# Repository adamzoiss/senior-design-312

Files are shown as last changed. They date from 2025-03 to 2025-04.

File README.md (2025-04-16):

# Senior Design Project - Team 312

**Share Point Quick Link:** [Project SharePoint](https://fsu-my.sharepoint.com/personal/amw21i_fsu_edu/_layouts/15/Doc.aspx?sourcedoc={c8d6e6cb-04f5-4a5c-a4a4-ac70581ecfba}&action=edit&wd=target%28Class%20Handouts.one%7C43749e4e-c570-4688-8d40-703e8b013bf2%2FSenior%20Design%20Projects%7C01b6a98f-3880-41ca-834b-d67c770890d6%2F%29&wdorigin=NavigationUrl)

---

**Table of Contents**

> _The links are clickable and will take you to that section or subsection._

- [**Operation Manual**](#operation-manual)

  - [How to start the device](#how-to-start-the-device)
  - [How to operate](#how-to-operate)

- [**Project Description**](#project-description)

  - [Overall Processes](#overall-processes)
  - [Audio Processing and Transmission](#audio-processing-and-transmission-of-data)
  - [Encryption/Decryption Information](#how-the-encryption-and-decryption-works)
  - [Materials](#materials)

- [**RPI Setup**](#rpi-setup)

  - [Flashing an OS](#flashing-an-os)
  - [How to SSH to rpi](#how-to-ssh-to-rpi)
  - [Driver Installation](#driver-installation)

- [**Coding Environment**](#coding-environment)

  - [Running the Code](#running-the-code)

- [**Creating a daemon**](#creating-a-daemon)

- [**Using Git**](#using-git)

  - [Setting up Git](#setting-up-git)
  - [Git usage](#git-usage)

- [**Documenting Python Code**](#documenting-python-code)

  - [Code Documentation](#code-documentation)
  - [Type Hinting Guide](#type-hinting-guide)

- [**Contributors**](#contributors)

**Resources:**

[KiCad](https://www.kicad.org/) - The circuit schematic and PCB design files are in the kicad folder.

[PEP 8 – Style Guide for Python Code](https://peps.python.org/pep-0008/#introduction) - Guideline for how to code in Python

[Python Project/Package Template](https://github.com/pypa/sampleproject) - To better understand the structure of the project, a template for python projects/packages can be viewed as a reference.

[Raspberry Pi pinout information](https://pinout.xyz/) - Useful for setting up buttons, switches, RF chip, etc. via the GPIO pins.

[Git Information](https://git-scm.com/book/en/v2) - Information on how to use git.

---

## Operation Manual:

A Guide on how to operate the end project will be discussed in this section.

### How to start the device:

Ideally a daemon could be used to start the program when booted up but there was a bug where the audio volume would only be set to 50%. The surefire way to get the device up and running is to first log in to the RPI5s and then configure it and and run the program manually:

```
alsamixer
```

- Set the volume to 100%

```
cd git/senior-design-312
penva
python src/managers/interface_manager.py
```

- This will start the program and show the logs in the terminal window

### How to operate

On the OLED screen there are two menus, Settings, and mode.

The Settings menu allows for the user to select and deselect the encryption for the device.

```
PENC - Packet Encryption: This is enables or disables the transceivers on board AES encryption.

DENC - Data Encryption: THis enables or disables the software encryption of the data.
```

In the Mode menu, the user can select the desired type of encryption for the data.

```
AES - Standard AES-256 Encryption

RSA - (NOT IMPLEMENTED) RSA Encryption

HYB - Hybrid Encryption method: RSA encrypted AES key
```

---

Volume Control

- The rotary encoder is used to change the onboard volume, which can be seen at the top left of the screen.

Selection of menu options

- The center button is used to select options in the menu.

Returning to the main menu

- The left button is used to return to the home screen.

Navigation

- The up and down buttons navigate through the menus.

Transmitting

- Pressing and holding the right button will start the transmission of the voice data from one device to the other. Releasing it will stop the transmission. Like a walkie-talkie, only one transceiver can be transmitting at a time.

---

## Project Description:

The purpose of the project is to have a hardware implementation for voice encryption. The approach taken was to use two Raspberry Pi 5's that are capable of encrypting and decrypting audio streams using AES or RSA. The encrypted stream is then sent to another Raspberry Pi via the RFM69 915MHz transceiver where it is then decrypted and played back. The functionality is like that of a rudimentary military grade radio (encrypted walkie talkie).

### Overall Processes:

To record the audio a button on the device is pressed, starting a thread to handle recording the audio and then transmitting it as shown in the diagram. The receiving device, upon receiving the RF signal and start sequence will start playing back the audio.

```mermaid
%%{init: {'theme': 'default', 'themeVariables': { 'fontSize': '18px', 'fontFamily': 'arial', 'edgeLabelBackground':'#ffffff'}, 'flowchart': {'diagramPadding': 40, 'curve': 'linear'}} }%%
flowchart LR
    %% Increase arrow thickness
    linkStyle default stroke-width:3px;

    subgraph sender["Audio Transmission"]
        record["Record Audio"] --> process["Process Audio"]
        process --> encode["Encode Audio"]
        encode --> encrypt["Encrypt Data"]
        encrypt --> send["Send Data"]
    end

    subgraph receiver["Reception and Playback"]
        receive["Receive Data"] --> decrypt["Decrypt Data"]
        decrypt --> decode["Decode Audio"]
        decode --> playback["Playback Audio"]
    end

    sender <==> receiver

    classDef default fill:#f0f8ff,stroke:#333,stroke-width:2px;
    classDef process fill:#e6ffe6,stroke:#333,stroke-width:2px;
    classDef encrypt fill:#ffe6e6,stroke:#333,stroke-width:2px;

    class record,process,encode,encrypt,send,receive,decrypt,decode,playback process;
```

### Audio Processing and Transmission of data:

[Diagrams and information](docs/design_flow_diagrams.md)

### How the encryption and decryption works:

This design used AES 256, RSA 4096, and a hybrid method that is outlined below:
[AES-256](docs/aes.md)
[RSA-4096](docs/rsa.md)

### Materials:

- [Raspberry Pi 5](https://www.adafruit.com/product/5813)
- [RPI UPS](https://www.amazon.com/Geekworm-X1200-Raspberry-Shutdown-Detection/dp/B0CRYVC8C5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)
- [ANO Directional Navigation](https://www.adafruit.com/product/5001)
- [RFM69HCW Transceiver](https://www.adafruit.com/product/3070)
- [Voice Bonnet](https://www.adafruit.com/product/4757)
- [OLED Display](https://www.amazon.com/dp/B0CHF7LHVT?ref=ppx_yo2ov_dt_b_fed_asin_title&th=1)
- [Speaker](https://www.adafruit.com/product/4227)

---

## RPI Setup:

### Flashing an OS:

1. Download the [Raspberry PI imager](https://www.raspberrypi.com/software/)

2. Select RPI 5 as device and Raspian 64-bit Lite as OS
   2.1 - For all the drivers for this project, a non desktop version must be used.

3. Customize settings before flashing

   - Name the device (ex. rpi5-312)
   - Set username (ex. team312)
   - Set password (ex. password)
   - Enable SSH in second tab
   - Finally flash the SD card with the OS

4. Plug SD card in, power on

---

### How to SSH to rpi:

_This step is optional_

Using powershell or terminal (must be on same network)

```bash
ssh [username]@[device name].local
```

- Follow steps to allow connection

- To make life simpler going forward, get the VS code extension _Remote Explorer_
  - Then follow steps to make a SSH connection in VS code.

---

### Driver Installation:

- This will update all the base packages and drivers for the Raspberry Pi.

  ```bash
  sudo apt update
  sudo apt -y upgrade
  sudo reboot
  ```

  - The following steps are for ease of installation of all the necessary packages/drivers for the RPI. Running the setup script will install all the packages as well as create a virtual python environment in the _senior-design-312_ directory.

  - This script also adds aliases to the .bashrc and exports the directory of the project to PYTHONPATH.

  ADDED ALIASES:

  - ptree - shows the tree of the directory, excludes some of the unimportant files.
  - penvca - Creates and activates a python virtual environment in _**.env**_
  - penva - Activates the python virtual environment.

  ```bash
  sudo apt install -y git
  mkdir git
  cd git
  git clone https://github.com/adamzoiss/senior-design-312.git
  cd senior-design-312
  cd setup_utils
  chmod +x setup.sh
  ./setup.sh
  ```

  - After the reboot, change the directory to _senior-design-312_ and run:

    ```bash
    penva
    ```

  All of the code should now be ready to run in the project.

---

## Coding Environment:

- When running the code ensure that the virtual environment is activated, if the setup script was run, in the project directory, run:
  ```bash
  penva
  ```

---

### Running the Code:

- Assuming the setup script was run to configure the RPI, ensure the virtual environment is activated (.env) to the left of your bash info, and run:

  ```bash
  python "path to python program"
  ```

- To run the tests and view the statistics, run:
  ```bash
  pytest
  ```

---

## Creating a daemon:

A daemon is a background process that runs continuously and independently of user interaction. It starts at boot (or when needed) and runs in the background, typically without a graphical interface. Daemons are often used for tasks like logging, networking, and running services (like web servers, audio managers, etc.). In the case of this project, a daemon is used to start the interface manager program on boot, and if it crashes, restarts the program.

- Creating a Systemd Service:
  ```bash
  sudo nano /etc/systemd/system/run-py-program.service
  ```
  > This should be pasted and modified to use the correct python path, program directory, and _pi_ username

```
[Unit]
Description=My Python Script Daemon
After=network.target sound.target
Wants=pulseaudio.service

[Service]
ExecStart=/home/pi/git/senior-design-312/.env/bin/python /home/pi/git/senior-design-312/src/managers/interface_manager.py
WorkingDirectory=/home/adamzoiss/git/senior-design-312
Environment="PYTHONPATH=/home/pi/git/senior-design-312"
User=pi
Group=pi
Restart=always
RestartSec=5
StandardOutput=append:/home/pi/git/senior-design-312/logs/system.log
StandardError=append:/home/pi/git/senior-design-312/logs/system.err

[Install]
WantedBy=multi-user.target
```

- Allow Systemd to use pulse audio:

  > By default, PulseAudio does not allow system services to access it. Run:

  ```
  sudo nano /etc/pulse/client.conf
  ```

  - At the end of the file, add:
    ```
    autospawn = yes
    ```
  - Then restart pulseaudio
    ```
    pulseaudio -k
    pulseaudio --start
    ```

- Enabling and staring the daemon:

  > To apply the changes made in the _.service_ file:

  ```
  sudo systemctl daemon-reload
  ```

  > To enable:

  ```
  sudo systemctl enable run-py-program.service
  ```

  > To start:

  ```
  sudo systemctl start run-py-program.service
  ```

  > View the status:

  ```
  sudo systemctl status run-py-program.service
  ```

  - More useful commands:
    ```
    sudo systemctl disable run-py-program.service
    sudo systemctl stop run-py-program.service
    sudo systemctl restart run-py-program.service
    ```

---

## Using Git:

Git is a distributed version control system designed to track changes in source code during software development. It allows multiple developers to collaborate on a project by managing code changes, maintaining a history of modifications, and enabling branching and merging workflows. Git ensures code integrity and simplifies collaboration by providing tools to resolve conflicts and review changes.

### Setting up Git:

- First set username and password via:

  ```bash
  git config --global user.name "github username"
  git config --global user.email "github email"
  ```

  - To verify they were set correctly:
    ```bash
    git config --global -l
    ```

  1. Make a github account (Make sure you set your username and email in global config)
  2. install _gh_ for github authentication
     ```bash
     sudo apt install gh
     gh auth login
     ```
  3. Follow steps and log in
  4. Verify with:
     ```bash
     gh auth status
     ```

---

### Git usage

- Always make edits in a `branch`, do not work directly on main. To see what branch is active:

  ```bash
  git branch
  ```

- To `checkout` an active branch with name _branchname_:

  ```bash
  git checkout branchname
  ```

- To create a new working branch:

  ```bash
  git checkout -b nameofbranch
  ```

- After making changes on a branch, save (`commit`) the changes by:

  ```bash
  git commit -a -m "brief description of what was done"
  ```

  - This saves the changes locally on your computer, to add (push the changes to github)
    ```bash
    git push origin branchname
    ```
    - Alternatively, If you want Git to automatically set upstream branches when pushing new local branches, you can enable:
      ```bash
      git config --global push.autoSetupRemote true
      ```
      This way, next time you create a new branch and push, Git will automatically set up the remote tracking branch. The command will now look like:
      ```bash
      git push
      ```

- Getting the most up to date code:
  - save changes that were done on your branch via a commit or stash
  - check out `main`
    ```bash
    git fetch
    ```
    ```bash
    git pull
    ```
  - the most up to date version of main is now what you see

---

## Documenting Python Code:

### Code Documentation

`numpy` style documentation is being used for this project.

**Example of a NumPy-style docstring:**

```python
import numpy as np

def compute_mean(arr):
    """
    Compute the mean of a NumPy array.

    Parameters
    ----------
    arr : numpy.ndarray
        Input array of numerical values.

    Returns
    -------
    float
        The mean (average) of the input array.

    Raises
    ------
    ValueError
        If the input is not a NumPy array.

    Examples
    --------
    >>> import numpy as np
    >>> arr = np.array([1, 2, 3, 4, 5])
    >>> compute_mean(arr)
    3.0
    """
    if not isinstance(arr, np.ndarray):
        raise ValueError("Input must be a NumPy array.")
    return arr.mean()
```

**Breakdown of the NumPy docstring format:**

- Short summary: The first line briefly describes what the function does.
- Parameters: List of arguments, types, and descriptions.
- Returns: Description of the return value and type.
- Raises: Expected exceptions that may be thrown.
- Examples: Demonstrates usage with `doctest`-style examples.

---

**Class with NumPy-style Docstrings**

This class represents a **Simple Linear Regression** model.

```python
import numpy as np

class SimpleLinearRegression:
    """
    A simple linear regression model using the least squares method.

    Attributes
    ----------
    coef_ : float
        The slope (coefficient) of the regression line.
    intercept_ : float
        The y-intercept of the regression line.

    Methods
    -------
    fit(X, y)
        Fits the model to the data.
    predict(X)
        Predicts values using the trained model.
    """

    def __init__(self):
        """
        Initializes the SimpleLinearRegression model with no trained parameters.
        """
        self.coef_ = None
        self.intercept_ = None

    def fit(self, X, y):
        """
        Fit the linear regression model to the given dataset.

        Parameters
        ----------
        X : numpy.ndarray
            Feature array of shape (n_samples,).
        y : numpy.ndarray
            Target array of shape (n_samples,).

        Raises
        ------
        ValueError
            If `X` and `y` have different lengths.

        Examples
        --------
        >>> import numpy as np
        >>> X = np.array([1, 2, 3, 4, 5])
        >>> y = np.array([2, 4, 6, 8, 10])
        >>> model = SimpleLinearRegression()
        >>> model.fit(X, y)
        """
        if len(X) != len(y):
            raise ValueError("X and y must have the same length.")

        X_mean = np.mean(X)
        y_mean = np.mean(y)

        num = np.sum((X - X_mean) * (y - y_mean))
        den = np.sum((X - X_mean) ** 2)

        self.coef_ = num / den
        self.intercept_ = y_mean - self.coef_ * X_mean

    def predict(self, X):
        """
        Predict the target values for given input data.

        Parameters
        ----------
        X : numpy.ndarray
            Feature array of shape (n_samples,).

        Returns
        -------
        numpy.ndarray
            Predicted values based on the trained model.

        Raises
        ------
        ValueError
            If the model has not been trained yet.

        Examples
        --------
        >>> import numpy as np
        >>> X = np.array([6, 7, 8])
        >>> model = SimpleLinearRegression()
        >>> model.fit(np.array([1, 2, 3, 4, 5]), np.array([2, 4, 6, 8, 10]))
        >>> model.predict(X)
        array([12., 14., 16.])
        """
        if self.coef_ is None or self.intercept_ is None:
            raise ValueError("Model is not trained. Call `fit` first.")

        return self.coef_ * X + self.intercept_
```

**NumPy Docstrings Benefits**

- Structured and readable: Clearly defines parameters, return values, and exceptions.
- Works with auto-documentation tools like Sphinx.
- Encourages best practices: Makes it easier to maintain and understand code.

---

### Type Hinting Guide:

1. Function Arguments & Return Types

   ```python
   def add(x: int, y: int) -> int:
       return x + y
   ```

   `x: int` and `y: int` specify that x and y should be integers.

   `-> int` means the function returns an integer.

2. Variable Annotations

   ```python
   name: str = "Alice"
   age: int = 25
   height: float = 5.9
   is_active: bool = True
   ```

3. Lists, Tuples, and Dictionaries

   Use `list`, `tuple`, and `dict` with generic types:

   ```python
   from typing import List, Tuple, Dict

   numbers: List[int] = [1, 2, 3, 4]
   point: Tuple[float, float] = (3.5, 7.2)
   person: Dict[str, int] = {"age": 30, "score": 95}
   ```

- `List[int]`: A list of integers.
- `Tuple[float, float]`: A tuple with two floats.
- `Dict[str, int]`: A dictionary with string keys and integer values.

4. Optional & Union Types

   **Optional Type (Allows `None`)**

   ```python
   from typing import Optional

   def get_user_name(user_id: int) -> Optional[str]:
       return "Alice" if user_id == 1 else None
   ```

   `Optional[str]` is equivalent to `Union[str, None]`.

   **Union (Multiple Types Allowed)**

   ```python
   from typing import Union

   def parse_value(value: Union[int, str]) -> str:
       return str(value)
   ```

   `Union[int, str]` means `value` can be an **int** or **str**.

5. Custom Classes as Types

   ```python
   class User:
       def __init__(self, name: str):
           self.name = name

   def greet(user: User) -> str:
       return f"Hello, {user.name}!"
   ```

   The function `greet` expects a `User` instance.

6. Callable (Hinting Functions)

   ```python
   from typing import Callable

   def execute(func: Callable[[int, int], int], x: int, y: int) -> int:
       return func(x, y)

   def multiply(a: int, b: int) -> int:
       return a * b

   result = execute(multiply, 3, 4)  # Returns 12
   ```

   `Callable[[int, int], int]` means a function that:

   - Takes two integeres.
   - Returns an integer.

7. Type Aliases (For Readability)

   ```python
   from typing import List

   Coordinates = List[Tuple[float, float]]  # Type alias

   route: Coordinates = [(10.0, 20.0), (30.5, 40.2)]
   ```

   Now, `Coordinates` can be used instead of `List[Tuple[float, float]]`.

8. Type Variables (For Generic Functions & Classes)

   _This is the same concept in C++ as `template <Typename T>`_

   ```python
   from typing import TypeVar, Generic

   T = TypeVar('T')  # Generic Type

   def repeat(value: T, times: int) -> List[T]:
       return [value] * times

   print(repeat("Hello", 3))  # ['Hello', 'Hello', 'Hello']
   ```

   Here:

   - `T` is a Type Variable that allows any type.
   - `repeat` works with any type, maintaining type safety.

9. TypedDict (For Struct-like Dictionaries)

   ```python
   from typing import TypedDict

   class UserDict(TypedDict):
       name: str
       age: int

   user: UserDict = {"name": "Alice", "age": 30}
   ```

   This ensures `user` has only the specified keys and types.

10. `Self` Type Hinting for Methods

    Introduced in Python 3.11, `Self` hints that a method returns an instance of its class.

    ```python
    from typing import Self

    class Animal:
        def set_name(self, name: str) -> Self:
            self.name = name
            return self  # Returns instance for method chaining

    dog = Animal().set_name("Buddy")
    ```

---

**Static Type Checking with `mypy`**

To enforce type checking, install mypy:

```bash
pip install mypy
```

Then run:

```bash
mypy my_script.py
```

This will flag type errors before runtime.

---

## Contributors:

Danielle Awoniyi : danielle1.awoniyi@famu.edu

Amira McKaige : amm21bc@fsu.edu

Amelia Wondracek : amw21i@fsu.edu

Travis Gabauer : tg21b@fsu.edu

Adam Zoiss : aez18@fsu.edu

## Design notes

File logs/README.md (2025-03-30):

This directory will hold the logs for the device.

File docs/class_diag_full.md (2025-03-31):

```mermaid
classDiagram
    class ThreadManager {
        - threads: dict[str, threading.Thread]
        - events: dict[str, threading.Event]
        - logger: logging
        + __init__()
        + start_thread(name, target, args)
        + stop_thread(name)
        + stop_all_threads()
        + pause_thread(name)
        + resume_thread(name)
        + is_running(name) bool
        + is_paused(name) bool
        + list_threads() list[str]
    }

    class CryptoManager {
        - key: bytes
        - iv: bytes
        - cipher: Cipher
        - key_file: str
        - public_key_file: str
        - private_key_file: str
        - logger: logging
        + __init__(key_file, public_key_file, private_key_file)
        + encrypt(data) bytes
        + decrypt(data) bytes
        - _load_key_iv() tuple
        - _load_rsa_keys() tuple
    }

    class BaseAudioManager {
        - CHUNK: int
        - FORMAT: pyaudio.paInt16
        - CHANNELS: int
        - RATE: int
        - audio: pyaudio.PyAudio
        - input_device_index: int
        - output_device_index: int
        - input_stream: pyaudio.Stream
        - output_stream: pyaudio.Stream
        - crypto_manager: CryptoManager
        - thread_manager: ThreadManager
        - logger: logging
        + __init__(thread_manager, frame_size, format, channels, sample_rate, in_device_index, out_device_index)
        + open_input_stream()
        + open_output_stream()
        + close_input_stream()
        + close_output_stream()
        + find_devices()
        + write_output(data, volume)
        + encode(data) bytes
        + decode(data) bytes
    }

    class AudioManager {
        + __init__(thread_manager, frame_size, format, channels, sample_rate, in_device_index, out_device_index)
        + monitor_audio(stop_event)
        + record_audio(output_file, monitoring)
        + record_encrypted_audio(output_file, monitoring)
        + encrypt_file(input_file, output_file)
        + decrypt_audio_file(input_file, output_file)
        + decrypt_audio_file_chunked(input_file, output_file)
        + record_encoded_audio()
        + play_encoded_audio()
    }
    AudioManager --|> BaseAudioManager

    class GPIOHandler {
        - handle: int
        + __init__(chip_number)
        + __del__()
        - _init_gpio()
        - _init_alerts()
        - _init_callbacks()
        - _cancel_callbacks()
    }

    class DisplayHandler {
        - display: SSD1306
        - MENU: Menu
        - MODE: Mode
        - DEBUG: Debug
        - CURRENT_SCREEN: Screen
        + __init__(display)
        + __del__()
        + get_screen(screen)
        + select(selection, x1, y1, x2, y2)
        + update_menu_selection(position)
    }

    class RFManager {
        - thread_manager: ThreadManager
        - audio_manager: BaseAudioManager
        - rfm69: RFM69
        - packet_queue: queue.Queue
        - pkt_buffer: bytes
        - frame_len: int
        - opus_buffer: bytes
        - logger: logging
        + __init__(handle, thread_manager, audio_manager)
        - _recv_pkt_callback(chip, gpio, level, timestamp)
        - _init_gpio_interrupts()
        + handle_packets(pause_event)
        + handle_input_stream(stop_event)
    }

    class InterfaceManager {
        - position: int
        - last_state_a: int
        - last_state_b: int
        - nav: DisplayHandler
        - audio_man: AudioManager
        - transmitter: RFManager
        - volume: int
        - logger: logging
        + __init__(thread_manager, chip_number)
        + __del__()
        - _encoder_callback(chip, gpio, level, timestamp)
        - _switch_callback(chip, gpio, level, timestamp)
    }
    InterfaceManager --|> GPIOHandler

    class SSD1306 {
        - width: int
        - height: int
        - pages: int
        - i2c_dev: int
        - image: PIL.Image.Image
        - draw: PIL.ImageDraw.ImageDraw
        + __init__(thread_manager, i2c_bus, width, height)
        + clear_and_turn_off()
        + write_command(cmd)
        + write_data(data)
        + initialize_display()
        + clear_screen()
        + display_image()
        + refresh_display()
        + clear_rectangle(x1, y1, x2, y2)
        + draw_text(text, x, y, font_size, font_file)
        + draw_line(x1, y1, x2, y2, fill)
        + draw_circle(x, y, radius, outline, fill)
        + draw_rotated_text(text, x, y, angle, font_size, font_file)
        + draw_constants()
    }

    class RFM69 {
        - tx_power: int
        - high_power: bool
        - handle: int
        + __init__(spi_bus, cs_pin, reset_pin, frequency, sync_word, preamble_length, encryption_key, high_power, baudrate, handle)
        + reset()
        + idle()
        + sleep()
        + listen()
        + transmit()
        + send(data, keep_listening, destination, node, identifier, flags)
        + receive(keep_listening, with_ack, timeout, with_header)
    }

    class Screen {
        - display: SSD1306
        - SELECTIONS: dict
        - CURRENT_SELECTION: int
        + __init__(display)
        + update_volume(volume_percentage)
        + select(selection)
        + draw_screen()
    }
    Screen <|-- Menu
    Screen <|-- Mode
    Screen <|-- Debug

    %% Interaction Diagram
    ThreadManager --> BaseAudioManager : manages threads
    BaseAudioManager --> CryptoManager : uses for encryption
    AudioManager --> BaseAudioManager : extends functionality
    RFManager --> ThreadManager : uses for thread management
    RFManager --> BaseAudioManager : uses for audio streaming
    GPIOHandler --> RFManager : provides GPIO alerts
    DisplayHandler --> ThreadManager : uses for thread management
    InterfaceManager --> DisplayHandler : manages display
    InterfaceManager --> AudioManager : manages audio
    InterfaceManager --> RFManager : manages RF communication
    InterfaceManager --> ThreadManager : uses for thread management
    SSD1306 --> DisplayHandler : provides display functionality
    RFM69 --> RFManager : provides RF communication
    Menu --> DisplayHandler : represents menu screen
    Mode --> DisplayHandler : represents mode selection screen
    Debug --> DisplayHandler : represents debug screen
```

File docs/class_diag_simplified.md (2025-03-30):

```mermaid
classDiagram
    class ThreadManager {
        "Manages threads and their lifecycle."
    }

    class CryptoManager {
        "Handles encryption and decryption."
    }

    class BaseAudioManager {
        "Manages audio input/output and encryption."
    }

    class AudioManager {
        "Extends BaseAudioManager with additional audio features."
    }
    AudioManager

    class GPIOHandler {
        "Handles GPIO setup and alerts."
    }

    class DisplayHandler {
        "Manages display navigation and rendering."
    }

    class RFManager {
        "Handles RF communication and audio streaming."
    }

    class InterfaceManager {
        "Integrates and manages all components for user interaction."
    }
    InterfaceManager --|> GPIOHandler

    %% Interaction Diagram
    BaseAudioManager --> ThreadManager : uses for thread management
    BaseAudioManager --> CryptoManager : uses for encryption
    AudioManager --> BaseAudioManager : extends functionality
    RFManager --> ThreadManager : uses for thread management
    RFManager --> BaseAudioManager : uses for audio streaming
    GPIOHandler --> RFManager : provides GPIO alerts
    DisplayHandler --> ThreadManager : uses for thread management
    InterfaceManager --> DisplayHandler : manages display
    InterfaceManager --> AudioManager : manages audio
    InterfaceManager --> RFManager : manages RF communication
    InterfaceManager --> ThreadManager : uses for thread management
```

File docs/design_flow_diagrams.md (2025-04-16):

# Audio Processing and Encryption Flow

## Detailed Flowchart Views

### Audio Processing Detail

The audio processing works to smooth the signal and make it so that if the user is far from the microphone, an audible sound is still played on the device.

```mermaid
%%{init: {'theme': 'default', 'themeVariables': { 'fontSize': '18px', 'fontFamily': 'arial', 'edgeLabelBackground':'#ffffff', 'tertiaryColor': '#f5f5f5'}, 'flowchart': {'diagramPadding': 40, 'curve': 'linear'}} }%%
flowchart TB
    %% Increase arrow thickness
    linkStyle default stroke-width:3px;

    audioIn["Input Audio"] --> rmsCalc["Calculate RMS Level"]
    rmsCalc --> noiseGate{"RMS > Noise Threshold?"}
    noiseGate -->|"No"| mute["Mute Output"]
    noiseGate -->|"Yes"| normalize["Apply Normalization"]
    normalize --> gainSmooth["Smooth Gain Changes"]
    gainSmooth --> volumeAdjust["Apply Volume Control"]
    mute --> output["Output Audio"]
    volumeAdjust --> output

    classDef default fill:#f9f0ff,stroke:#333,stroke-width:2px;
    classDef decision fill:#fffacd,stroke:#333,stroke-width:2px;
    classDef output fill:#e6ffe6,stroke:#333,stroke-width:2px;

    class noiseGate decision;
    class output output;
```

### Packet Fragmentation and Transmission Process

Since the RF transceiver is limited in it's transmission speed, the audio must be encoded instead of sent raw, this reduces the amount of data that is needed to be transferred.

```mermaid
%%{init: {'theme': 'default', 'themeVariables': { 'fontSize': '18px', 'fontFamily': 'arial', 'edgeLabelBackground':'#ffffff'}, 'flowchart': {'diagramPadding': 40, 'curve': 'linear'}} }%%
flowchart TB
    %% Increase arrow thickness
    linkStyle default stroke-width:3px;

    audioFrame["Encoded Audio Frame"] --> sizeCheck{"Size > Max Packet Size (60 bytes)"}

    sizeCheck -->|"No"| singlePacket["Create Single Packet"]
    sizeCheck -->|"Yes"| fragment["Fragment Data"]

    fragment --> packetHeader1["Add Packet 1 Header"]
    fragment --> packetHeader2["Add Packet 2 Header"]
    fragment --> morePackets["...Additional Packets..."]

    packetHeader1 --> encrypt1["Encrypt Packet 1"]
    packetHeader2 --> encrypt2["Encrypt Packet 2"]
    morePackets --> encryptMore["Encrypt Additional Packets"]

    singlePacket --> encryptSingle["Encrypt Single Packet"]

    encrypt1 --> txQueue["Transmission Queue"]
    encrypt2 --> txQueue
    encryptMore --> txQueue
    encryptSingle --> txQueue

    txQueue --> send["Send Packets Sequentially"]

    classDef default fill:#f0f8ff,stroke:#333,stroke-width:2px;
    classDef decision fill:#fffacd,stroke:#333,stroke-width:2px;
    classDef process fill:#e6ffe6,stroke:#333,stroke-width:2px;
    classDef encrypt fill:#ffe6e6,stroke:#333,stroke-width:2px;

    class sizeCheck decision;
    class encrypt1,encrypt2,encryptMore,encryptSingle encrypt;
    class fragment,singlePacket,txQueue process;
```

### Packet Reassembly Process on Receiver

Since the audio data is broken up while being sent, it must be reassembled before it can be played back.

```mermaid
%%{init: {'theme': 'default', 'themeVariables': { 'fontSize': '18px', 'fontFamily': 'arial', 'edgeLabelBackground':'#ffffff'}, 'flowchart': {'diagramPadding': 40, 'curve': 'linear'}} }%%
flowchart TB
    %% Increase arrow thickness
    linkStyle default stroke-width:3px;

    receive["Receive Packet"] --> decrypt["Decrypt Packet"]

    decrypt --> headerCheck{"Is Fragment?"}

    headerCheck -->|"No"| processComplete["Process Complete Packet"]
    headerCheck -->|"Yes"| bufferStorage["Store in Fragment Buffer"]

    bufferStorage --> completeCheck{"All Fragments Received?"}

    completeCheck -->|"No"| waitMore["Wait for More Fragments"]
    completeCheck -->|"Yes"| reassemble["Reassemble Complete Data"]

    waitMore --> receive

    reassemble --> processComplete

    processComplete --> audioDecoding["Decode Audio"]

    classDef default fill:#f0f8ff,stroke:#333,stroke-width:2px;
    classDef decision fill:#fffacd,stroke:#333,stroke-width:2px;
    classDef process fill:#e6ffe6,stroke:#333,stroke-width:2px;
    classDef decrypt fill:#ffe6e6,stroke:#333,stroke-width:2px;

    class headerCheck,completeCheck decision;
    class decrypt decrypt;
    class reassemble,processComplete,bufferStorage process;
```

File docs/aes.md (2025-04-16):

# AES Encryption and Decryption

## AES-256 Overview

AES (Advanced Encryption Standard) is a symmetric encryption algorithm that uses the same key for both encryption and decryption. AES-256 refers to the use of a 256-bit key size, which is currently considered secure against brute force attacks.

## Simplified AES-256 Process

```mermaid
%%{init: {'theme': 'default', 'themeVariables': { 'fontSize': '18px', 'fontFamily': 'arial', 'edgeLabelBackground':'#ffffff', 'tertiaryColor': '#f5f5f5'}, 'flowchart': {'diagramPadding': 40, 'curve': 'linear'}} }%%
graph TB
    %% Define styles
    classDef plaintext fill:#d4f1f9,stroke:#0e5f8a,stroke-width:2px
    classDef key fill:#ffe6cc,stroke:#d79b00,stroke-width:2px
    classDef process fill:#d5e8d4,stroke:#82b366,stroke-width:2px
    classDef ciphertext fill:#f8cecc,stroke:#b85450,stroke-width:2px

    %% Simplified encryption flow
    P[Plaintext] --> KE[Key Expansion]
    SK[Secret Key 256 bits] --> KE
    P --> BM[Bit Manipulation 14 Rounds]
    KE --> BM
    BM --> C[Ciphertext]

    %% Simplified decryption flow
    C --> RBM[Reverse Bit Manipulation 14 Rounds]
    KE --> RBM
    RBM --> P2[Plaintext]

    %% Apply styles
    class P,P2 plaintext
    class SK key
    class KE,BM,RBM process
    class C ciphertext
```

## Key Components of AES-256

1. **Secret Key**: A 256-bit (32-byte) key used for both encryption and decryption
2. **Key Expansion**: Process that derives multiple round keys from the original secret key
3. **Bit Manipulation**: AES-256 uses 14 rounds of complex bit operations including:
   - Byte substitution
   - Row shifting
   - Column mixing
   - Key addition

## CFB Mode (Cipher Feedback)

In our implementation, we use AES in CFB (Cipher Feedback) mode, which turns the block cipher into a stream cipher, making it ideal for encrypting continuous data streams like audio.

```mermaid
%%{init: {'theme': 'default', 'themeVariables': { 'fontSize': '18px', 'fontFamily': 'arial', 'edgeLabelBackground':'#ffffff', 'tertiaryColor': '#f5f5f5'}, 'flowchart': {'diagramPadding': 40, 'curve': 'linear'}} }%%
graph LR
    %% Define styles
    classDef plaintext fill:#d4f1f9,stroke:#0e5f8a,stroke-width:2px
    classDef key fill:#ffe6cc,stroke:#d79b00,stroke-width:2px
    classDef process fill:#d5e8d4,stroke:#82b366,stroke-width:2px
    classDef ciphertext fill:#f8cecc,stroke:#b85450,stroke-width:2px
    classDef iv fill:#e1d5e7,stroke:#9673a6,stroke-width:2px

    %% Simplified Encryption
    subgraph Encryption
        IV1[Initialization Vector] --> E1[AES-256 Bit Manipulation]
        K1[Secret Key] --> E1
        E1 --> EO1[Encrypted Output]
        P1[Plaintext Block 1] --> XOR1((XOR))
        EO1 --> XOR1
        XOR1 --> C1[Ciphertext Block 1]

        C1 -->|Feedback| E2[AES-256 Bit Manipulation]
        K1 --> E2
        E2 --> EO2[Encrypted Output]
        P2[Plaintext Block 2] --> XOR2((XOR))
        EO2 --> XOR2
        XOR2 --> C2[Ciphertext Block 2]
    end

    %% Simplified Decryption
    subgraph Decryption
        IV2[Initialization Vector] --> E3[AES-256 Bit Manipulation]
        K2[Secret Key] --> E3
        E3 --> EO3[Encrypted Output]
        C3[Ciphertext Block 1] --> XOR3((XOR))
        EO3 --> XOR3
        XOR3 --> P3[Plaintext Block 1]

        C3 -->|Feedback| E4[AES-256 Bit Manipulation]
        K2 --> E4
        E4 --> EO4[Encrypted Output]
        C4[Ciphertext Block 2] --> XOR4((XOR))
        EO4 --> XOR4
        XOR4 --> P4[Plaintext Block 2]
    end

    %% Apply styles
    class IV1,IV2 iv
    class K1,K2 key
    class P1,P2,P3,P4 plaintext
    class E1,E2,E3,E4,EO1,EO2,EO3,EO4,XOR1,XOR2,XOR3,XOR4 process
    class C1,C2,C3,C4 ciphertext
```

## Advantages for Audio Encryption

- **Stream-based**: Can encrypt data of arbitrary length without padding
- **Partial Block Processing**: Efficient for real-time audio processing
- **Error Propagation**: Limited to one block, minimizing impact on audio quality
- **No Padding Required**: Simplifies the processing pipeline for continuous audio streams

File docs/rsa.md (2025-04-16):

# RSA Encryption and Decryption

## RSA Overview

RSA (Rivest-Shamir-Adleman) is an asymmetric encryption algorithm that uses a pair of keys: a public key for encryption and a private key for decryption. This allows secure communication without having to share a secret key beforehand.

## Simplified RSA Process

```mermaid
%%{init: {'theme': 'default', 'themeVariables': { 'fontSize': '18px', 'fontFamily': 'arial', 'edgeLabelBackground':'#ffffff', 'tertiaryColor': '#f5f5f5'}, 'flowchart': {'diagramPadding': 40, 'curve': 'linear'}} }%%
graph TB
    %% Define styles
    classDef plaintext fill:#d4f1f9,stroke:#0e5f8a,stroke-width:2px
    classDef keys fill:#ffe6cc,stroke:#d79b00,stroke-width:2px
    classDef process fill:#d5e8d4,stroke:#82b366,stroke-width:2px
    classDef ciphertext fill:#f8cecc,stroke:#b85450,stroke-width:2px

    %% Key generation
    KG[Key Generation]
    PK[Public Key]
    SK[Private Key]
    KG --> PK
    KG --> SK

    %% Encryption flow
    P[Plaintext Message] --> E[Mathematical Operation]
    PK --> E
    E --> C[Ciphertext]

    %% Decryption flow
    C --> D[Mathematical Operation]
    SK --> D
    D --> P2[Plaintext Message]

    %% Apply styles
    class P,P2 plaintext
    class PK,SK keys
    class KG,E,D process
    class C ciphertext
```

## Key Components of RSA

1. **Key Generation**: The creation of a mathematically linked public and private key pair
2. **Public Key**: Shared openly and used to encrypt messages
3. **Private Key**: Kept secret and used to decrypt messages
4. **Mathematical Operations**: Based on the difficulty of factoring large prime numbers
5. **Modular Arithmetic**: Mathematical operations performed with remainders

## RSA Key Generation

```mermaid
%%{init: {'theme': 'default', 'themeVariables': { 'fontSize': '18px', 'fontFamily': 'arial', 'edgeLabelBackground':'#ffffff', 'tertiaryColor': '#f5f5f5'}, 'flowchart': {'diagramPadding': 40, 'curve': 'linear'}} }%%
flowchart TB
    %% Define styles
    classDef operand fill:#ffe6cc,stroke:#d79b00,stroke-width:2px
    classDef operation fill:#d5e8d4,stroke:#82b366,stroke-width:2px
    classDef result fill:#f8cecc,stroke:#b85450,stroke-width:2px

    %% Key generation steps
    P1[Choose large prime p] --> M[Multiply]
    P2[Choose large prime q] --> M
    M --> N[n = p × q]

    P1 --> C1["Calculate (p-1)"]
    P2 --> C2["Calculate (q-1)"]
    C1 --> T[Multiply]
    C2 --> T
    T --> PHI["φ(n) = (p-1)(q-1)"]

    PHI --> CE["Choose e"]
    CE --> E["Public exponent e\n(relatively prime to φ(n))"]

    PHI --> CD["Calculate d"]
    E --> CD
    CD --> D["Private exponent d\n(d × e ≡ 1 mod φ(n))"]

    N --> PUB["Public Key (e, n)"]
    E --> PUB

    N --> PRIV["Private Key (d, n)"]
    D --> PRIV

    %% Apply styles
    class P1,P2,PHI,E,D operand
    class M,C1,C2,T,CE,CD operation
    class N,PUB,PRIV result
```

## RSA in Action

```mermaid
%%{init: {'theme': 'default', 'themeVariables': { 'fontSize': '18px', 'fontFamily': 'arial', 'edgeLabelBackground':'#ffffff', 'tertiaryColor': '#f5f5f5'}, 'flowchart': {'diagramPadding': 40, 'curve': 'linear'}} }%%
graph LR
    %% Define styles
    classDef plaintext fill:#d4f1f9,stroke:#0e5f8a,stroke-width:2px
    classDef key fill:#ffe6cc,stroke:#d79b00,stroke-width:2px
    classDef process fill:#d5e8d4,stroke:#82b366,stroke-width:2px
    classDef ciphertext fill:#f8cecc,stroke:#b85450,stroke-width:2px

    %% Encryption process
    subgraph Encryption
        M[Message M] --> E["Encrypt: C = M^e mod n"]
        PK["Public Key (e, n)"] --> E
        E --> C[Ciphertext C]
    end

    %% Decryption process
    subgraph Decryption
        C2[Ciphertext C] --> D["Decrypt: M = C^d mod n"]
        SK["Private Key (d, n)"] --> D
        D --> M2[Message M]
    end

    %% Apply styles
    class M,M2 plaintext
    class PK,SK key
    class E,D process
    class C,C2 ciphertext
```

## Advantages and Limitations of RSA

### Advantages

- **No Shared Secret**: Communicating parties don't need to share a secret key in advance
- **Digital Signatures**: Can be used to verify the sender's identity
- **Key Distribution**: Simplifies secure key exchange over insecure channels

### Limitations

- **Performance**: Significantly slower than symmetric encryption like AES
- **Key Size**: Requires large keys (2048+ bits) for security
- **Data Size**: Limited to encrypting data smaller than the key size
- **Quantum Vulnerability**: Vulnerable to quantum computing attacks

## Hybrid Encryption

Due to RSA's performance limitations, it's often used in a hybrid approach with symmetric encryption:

```mermaid
%%{init: {'theme': 'default', 'themeVariables': { 'fontSize': '18px', 'fontFamily': 'arial', 'edgeLabelBackground':'#ffffff', 'tertiaryColor': '#f5f5f5'}, 'flowchart': {'diagramPadding': 40, 'curve': 'linear'}} }%%
graph TD
    %% Define styles
    classDef plaintext fill:#d4f1f9,stroke:#0e5f8a,stroke-width:2px
    classDef key fill:#ffe6cc,stroke:#d79b00,stroke-width:2px
    classDef process fill:#d5e8d4,stroke:#82b366,stroke-width:2px
    classDef ciphertext fill:#f8cecc,stroke:#b85450,stroke-width:2px

    %% Encryption flow
    M[Message] --> AE[AES Encryption]
    AK[Random AES Key] --> AE
    AE --> C[Encrypted Message]

    AK --> RE[RSA Encryption]
    PK[RSA Public Key] --> RE
    RE --> EK[Encrypted AES Key]

    %% Decryption flow
    EK --> RD[RSA Decryption]
    SK[RSA Private Key] --> RD
    RD --> AK2[AES Key]

    C --> AD[AES Decryption]
    AK2 --> AD
    AD --> M2[Original Message]

    %% Apply styles
    class M,M2,AK,AK2 plaintext
    class PK,SK key
    class AE,RE,RD,AD process
    class C,EK ciphertext
```

This hybrid approach provides:

- The security of RSA for key exchange
- The performance of AES for data encryption
- The ability to encrypt data of any size efficiently

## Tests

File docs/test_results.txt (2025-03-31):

This was run on macos, for real results run on rpi:

pytest > docs/test_results.txt

============================= test session starts ==============================
platform darwin -- Python 3.13.2, pytest-8.3.5, pluggy-1.5.0 -- /Users/adamzoiss/Documents/git/senior-design-312/.env/bin/python3.13
cachedir: .pytest_cache
rootdir: /Users/adamzoiss/Documents/git/senior-design-312
configfile: pytest.ini
testpaths: tests
collecting ... collected 12 items

tests/src/managers/test_audio_manager.py::test_creation PASSED           [  8%]
tests/src/managers/test_base_audio_manager.py::test_creation PASSED      [ 16%]
tests/src/managers/test_base_audio_manager.py::test_stream PASSED        [ 25%]
tests/src/managers/test_base_audio_manager.py::test_encryption PASSED    [ 33%]
tests/src/managers/test_base_audio_manager.py::test_decryption PASSED    [ 41%]
tests/src/managers/test_base_audio_manager.py::test_encryption_performance 
--- Starting encryption performance test ---

Encryption Performance Metrics:
Total data processed: 0.27 MB
Total time: 0.0006 seconds
Throughput: 471.11 MB/s
Average time per chunk (1920 bytes): 3.89 µs

---  Ending encryption performance test  ---
PASSED [ 50%]
tests/src/managers/test_base_audio_manager.py::test_decryption_performance 
--- Starting decryption performance test ---

Decryption Performance Metrics:
Total data processed: 0.27 MB
Total time: 0.0005 seconds
Throughput: 496.88 MB/s
Average time per chunk (1920 bytes): 3.69 µs

---  Ending decryption performance test  ---
PASSED [ 58%]
tests/src/managers/test_crypto_manager.py::test_creation PASSED          [ 66%]
tests/src/managers/test_rf_manager.py::test_rf_manager_initialization PASSED [ 75%]
tests/src/managers/test_rf_manager.py::test_packet_sending 
--- Starting RF packet sending performance test ---

RF Packet Sending Performance:
Total packets sent: 1000
Total data sent: 58.59 KB
Total time: 4.5083 seconds
Throughput: 103.97 kbps
Average time per packet: 4.51 ms
Packets per second: 221.81
Mock RFM69 stats: {'packets_sent': 1000, 'packets_received': 0, 'bytes_sent': 60000, 'bytes_received': 0, 'send_queue_size': 1000, 'receive_queue_size': 1000}

--- Ending RF packet sending performance test ---
PASSED        [ 83%]
tests/src/managers/test_rf_manager.py::test_packet_receiving 
--- Starting RF packet receiving performance test ---

RF Packet Receiving Performance:
Total packets received: 1000
Total data received: 58.59 KB
Total time: 4.4919 seconds
Throughput: 104.36 kbps
Average time per packet: 4.49 ms
Packets per second: 222.63
Mock RFM69 stats: {'packets_sent': 0, 'packets_received': 1000, 'bytes_sent': 0, 'bytes_received': 60000, 'send_queue_size': 0, 'receive_queue_size': 0}

--- Ending RF packet receiving performance test ---
PASSED      [ 91%]
tests/src/managers/test_rf_manager.py::test_end_to_end_transmission 
--- Starting end-to-end RF transmission test ---

End-to-End RF Transmission Performance:
Total audio frames: 100
Complete frames decoded: 98
Total packets sent: 283
Total packets received: 283
Raw audio size: 187.50 KB
Encoded size: 12.51 KB (compression ratio: 14.99x)
Decoded audio size: 185.62 KB
Total time: 2.6102 seconds
Throughput: 38.34 kbps
Packets per second: 108.42

--- Ending end-to-end RF transmission test ---
PASSED [100%]

============================= 12 passed in 14.92s ==============================

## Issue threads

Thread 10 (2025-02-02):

Create idea for physical interface options

adamzoiss, 2025-02-02:
The GPIO pins along with physical like buttons, switches, rotary encoders, sliders, can be used to control how the program operates.

A design for how that might work/look should be drawn up on paper showing connections and functionality.

examples.)
(Hold button - send encrypted voice stream via rf
 Release - stop sending)

(Switch - change encryption type)

(Slider/Rotary encoder - Control volume)

Closed 2025-03-07.

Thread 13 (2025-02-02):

3D print case/enclosure?

adamzoiss, 2025-02-02:
FSU Innovation Hub has a lot of 3D printers.

Could 3D print a protective case for the rpi.

Find out software and how to print.

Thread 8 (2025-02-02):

tests/interface_testing.py - Create file and test GPIO pins

adamzoiss, 2025-02-02:
Create a file to test GPIO functionality.

Use the "lgpio" package to test and validate that the GPIO pins work.  This can be done by using a breadboard, jumper cables, buttons, switches, etc.

A multimeter in continuity mode can also be used.

Closed 2025-03-07.

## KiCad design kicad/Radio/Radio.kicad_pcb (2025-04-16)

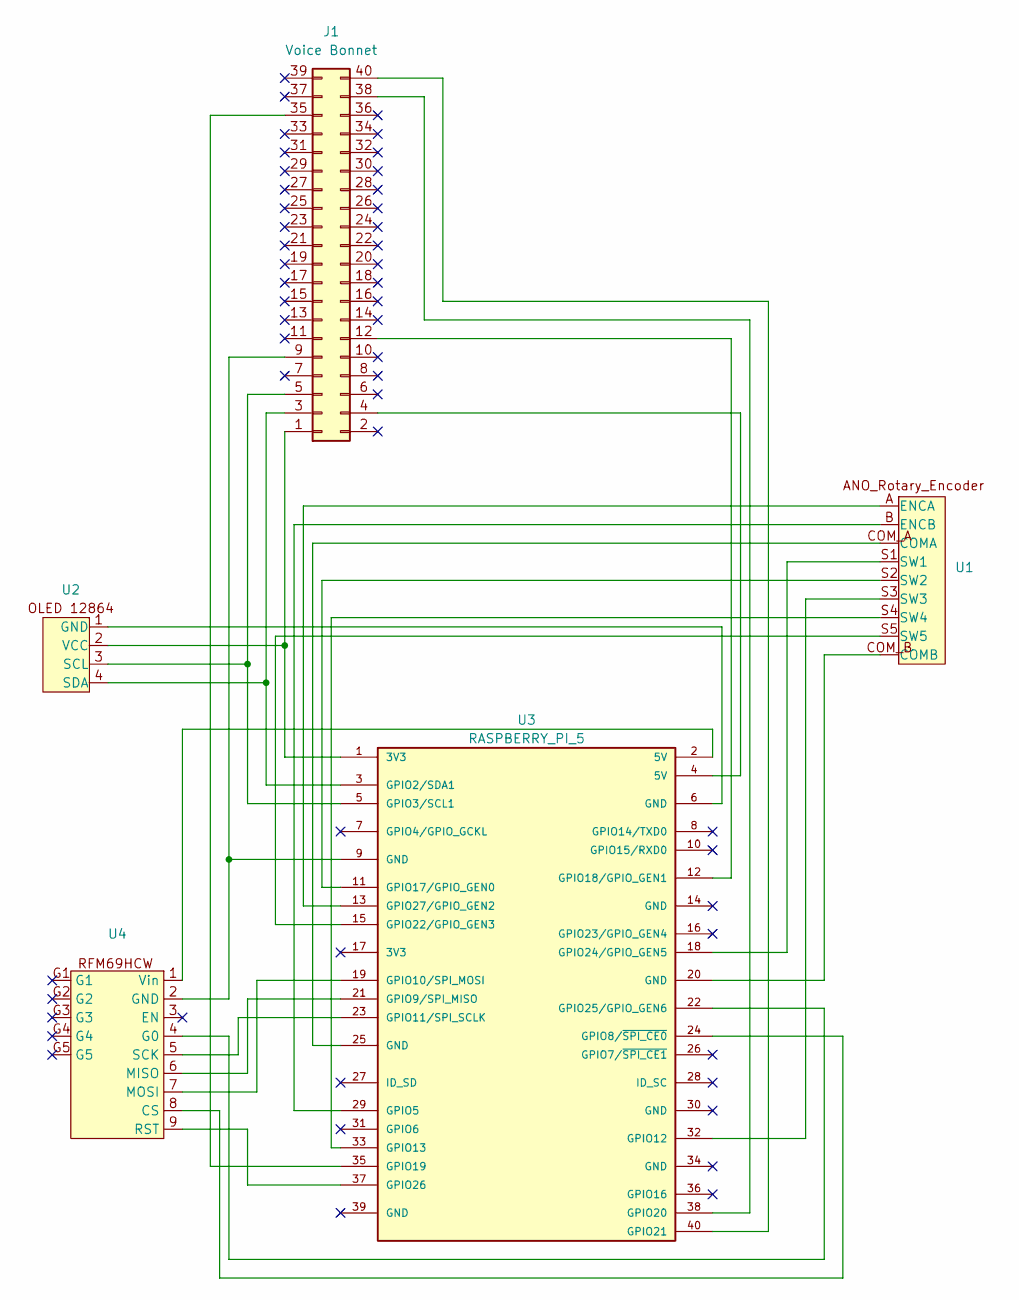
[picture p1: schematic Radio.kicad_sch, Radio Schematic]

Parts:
J1: Voice Bonnet; Voice_Bonnet
U1: ANO
U2: PinHeader_1x04_P2.54mm_Vertical
U3: RASPBERRY_PI_5; MODULE_RASPBERRY_PI_4B_4GB; PARTREV 4
U4: rfm69

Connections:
unnamed: J1.1, U2.2 (VCC), U3.1 (3V3)
unnamed: J1.3, U2.4 (SDA), U3.3 (GPIO2/SDA1)
unnamed: J1.4, U3.4 (5V)
unnamed: J1.5, U2.3 (SCL), U3.5 (GPIO3/SCL1)
unnamed: J1.9, U3.9 (GND), U4.2 (GND)
unnamed: J1.12, U3.12 (GPIO18/GPIO_GEN1)
unnamed: J1.35, U3.35 (GPIO19)
unnamed: J1.38, U3.38 (GPIO20)
unnamed: J1.40, U3.40 (GPIO21)
unnamed: U1.COM_A (COMA), U3.25 (GND)
unnamed: U1.COM_B (COMB), U3.20 (GND)
unnamed: U1.A (ENCA), U3.13 (GPIO27/GPIO_GEN2)
unnamed: U1.B (ENCB), U3.29 (GPIO5)
unnamed: U1.S1 (SW1), U3.18 (GPIO24/GPIO_GEN5)
unnamed: U1.S2 (SW2), U3.11 (GPIO17/GPIO_GEN0)
unnamed: U1.S3 (SW3), U3.32 (GPIO12)
unnamed: U1.S4 (SW4), U3.33 (GPIO13)
unnamed: U1.S5 (SW5), U3.15 (GPIO22/GPIO_GEN3)
unnamed: U2.1 (GND), U3.6 (GND)
unnamed: U3.24 (GPIO8/~SPI_CE0), U4.8 (CS)
unnamed: U3.21 (GPIO9/SPI_MISO), U4.6 (MISO)
unnamed: U3.19 (GPIO10/SPI_MOSI), U4.7 (MOSI)
unnamed: U3.23 (GPIO11/SPI_SCLK), U4.5 (SCK)
unnamed: U3.22 (GPIO25/GPIO_GEN6), U4.4 (G0)
unnamed: U3.37 (GPIO26), U4.9 (RST)
unnamed: U3.2 (5V), U4.1 (Vin)

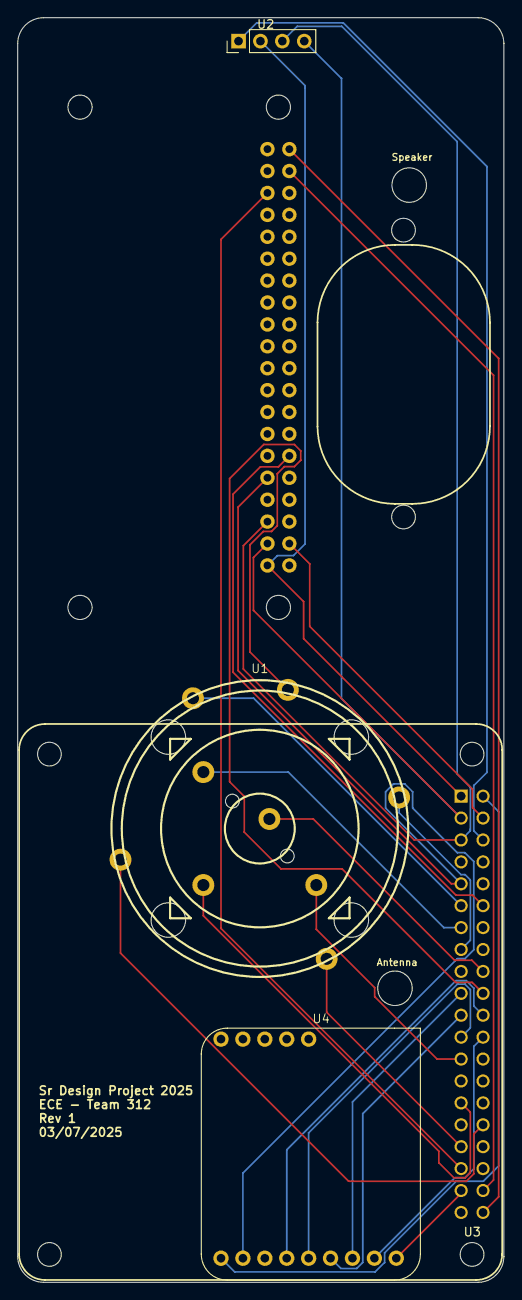
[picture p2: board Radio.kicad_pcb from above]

Board: 2 copper layers, 56.4 x 146.6 mm, 5 parts (1 on the bottom side), 26 nets.

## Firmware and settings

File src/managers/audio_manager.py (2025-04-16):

"""
Senior Project : Hardware Encryption Device
Team 312
File : audio_manager.py
Description: This is the audio driver for the project. By itself it is able to record and monitor
    audio from a usb mic/headphone set. It is also able to encrypt and decrypt.
    The audio file or stream itself may be encrypted and decrypted. This provides a lot of
    flexibility down the line.
"""

import pyaudio
import wave
import opuslib
import numpy as np
import os
import threading
import struct

from src.managers.base_audio_manager import *

# Path and file names for the file types.
PATH = "./audio_files/"
AUDIO_FILE = PATH + "audio.wav"
ENCRYPTED_AUDIO_FILE = PATH + "encrypted_audio.bin"
ENCRYPTED_AUDIO_STREAM_FILE = PATH + "encrypted_audio_stream.wav"
DECRYPTED_AUDIO_FILE = PATH + "decrypted_audio.wav"
DECRYPTED_AUDIO_STREAM_FILE = PATH + "decrypted_audio_stream.wav"
RSA_ENCRYPTED_AUDIO_FILE = PATH + "RSA_encrypted_audio.bin"
RSA_ENCRYPTED_AUDIO_STREAM_FILE = PATH + "RSA_encrypted_audio_stream.wav"
RSA_DECRYPTED_AUDIO_FILE = PATH + "RSA_decrypted_audio.wav"
RSA_DECRYPTED_AUDIO_STREAM_FILE = PATH + "RSA_decrypted_audio_stream.wav"
HYBRID_ENCRYPTED_AUDIO_FILE = PATH + "HYBRID_encrypted_audio.bin"
HYBRID_ENCRYPTED_AUDIO_STREAM_FILE = PATH + "HYBRID_encrypted_audio_stream.wav"
HYBRID_DECRYPTED_AUDIO_FILE = PATH + "HYBRID_decrypted_audio.wav"
HYBRID_DECRYPTED_AUDIO_STREAM_FILE = PATH + "HYBRID_decrypted_audio_stream.wav"


class AudioManager(BaseAudioManager):
    """
    Driver that handles the audio input and output.
    The user must specify the index of the USB mic and headphones.
    To discover what index, run the driver and select option 3.

    Attributes
    ----------
    CHUNK : int
        Number of audio frames per buffer. (Lower means less latency)
    FORMAT : pyaudio.paInt16
        Format of audio data (16-bit audio in this case).
    CHANNELS : int
        Number of audio channels (1 for mono).
    RATE : int
        Sampling rate in Hz.

    audio : pyaudio.PyAudio
        PyAudio instance for managing audio streams.
    input_device_index : int or None
        Index of the input device.
    output_device_index : int or None
        Index of the output device.

    input_stream : pyaudio.Stream or None
        Stream object for audio input.
    output_stream : pyaudio.Stream or None
        Stream object for audio output.

    crypto_manager : CryptoManager
        Instance of the CryptoManager for encryption and decryption.
    """

    def __init__(
        self,
        thread_manager: ThreadManager,
        frame_size=FRAME_SIZE,
        format=FORMAT,
        channels=CHANNELS,
        sample_rate=RATE,
        in_device_index=INPUT_DEV_INDEX,
        out_device_index=OUTPUT_DEV_INDEX,
    ):
        """
        Initialize the AudioManager instance and configure default audio settings.
        """

        # Call the BaseAudioManager init
        super().__init__(
            thread_manager,
            frame_size,
            format,
            channels,
            sample_rate,
            in_device_index,
            out_device_index,
        )

        # Set up logging
        self.logger: logging = Logger(
            "AudioManager",
            console_level=logging.INFO,
            console_logging=EN_CONSOLE_LOGGING,
        )

        self.logger.info("AudioManager initialized.")

    def monitor_audio(self, stop_event: threading.Event):
        """
        Continuously monitor and play audio from the microphone.

        This method plays the audio captured from the microphone through the output device.

        Raises
        ------
        KeyboardInterrupt
            Stops monitoring when Ctrl+C is pressed.
        """
        self.logger.info(f"Monitoring audio | {self.volume}%")

        try:
            # Open the streams
            if self.audio.get_device_count() == 0:
                self.logger.warning("Can not open streams if no audio device.")
                return
            else:
                self.open_streams()

            # Monitor the audio
            while not stop_event.is_set():
                data = self.input_stream.read(
                    self.CHUNK, exception_on_overflow=False
                )
                ###############################################################
                # Convert to NumPy array
                audio_data = np.frombuffer(data, dtype=np.int16)
                # Apply volume scaling
                volume_scalar = (self.volume / 100) * 4
                audio_data = (audio_data * volume_scalar).astype(np.int16)
                # Convert back to bytes
                data = audio_data.tobytes()
                ###############################################################
                # Encrypt --> decrypt --> write to output stream
                encrypted_data = self.crypto_manager.encrypt(data)
                decrypted_data = self.crypto_manager.decrypt(encrypted_data)
                self.output_stream.write(decrypted_data)
        except KeyboardInterrupt:
            self.logger.info("\nMonitoring stopped.\n")
        finally:
            self.close_streams()
            self.logger.info("Monitoring stopped.")

    def record_audio(self, output_file=AUDIO_FILE, monitoring=False):
        """
        Record audio from the microphone and save it to a WAV file.

        Parameters
        ----------
        output_file : str, optional
            The name of the output WAV file (default is "recorded_audio.wav").
        monitoring : bool, optional
            If True, play back the recorded audio while recording (default is False).
        """
        # Get the parent directory of the current script
        parent_dir = get_proj_root()
        # Create the target folder path in the parent directory
        output_dir = os.path.join(parent_dir, PATH)
        # Construct the full path for the output file
        output_file_path = os.path.join(
            output_dir, os.path.basename(output_file)
        )
        # Ensure that the path exists, and if doesn't is created.
        ensure_path(str(output_dir))

        try:
            self.logger.debug("Recording... Press Ctrl+C to stop.")
            self.open_streams()
            frames = []  # List to store recorded frames
            try:
                while True:
                    # Capture audio data from the input stream
                    data = self.input_stream.read(
                        self.CHUNK, exception_on_overflow=False
                    )
                    frames.append(data)
                    # Playback the captured data
                    if monitoring:
                        self.output_stream.write(data)
            except KeyboardInterrupt:
                self.logger.debug("\nRecording stopped.")
                # Save recorded audio to a WAV file
                with wave.open(output_file, "wb") as wf:
                    wf.setnchannels(self.CHANNELS)
                    wf.setsampwidth(self.audio.get_sample_size(self.FORMAT))
                    wf.setframerate(self.RATE)
                    wf.writeframes(b"".join(frames))
                self.logger.debug(f"Audio saved to {output_file}")
        except Exception as e:
            self.logger.error(f"An error occurred: {e}")
        finally:
            self.close_streams()

    def record_encrypted_audio(
        self, output_file=ENCRYPTED_AUDIO_STREAM_FILE, monitoring=False
    ):
        """
        Record audio, encrypt it, and save it to a file.

        Parameters
        ----------
        output_file : str, optional
            The name of the output encrypted file (default is "recorded_audio_encrypted.wav").
        monitoring : bool, optional
            If True, play back the recorded audio while recording (default is False).
        """
        # Get the parent directory of the current script
        parent_dir = get_proj_root()
        # Create the target folder path in the parent directory
        output_dir = os.path.join(parent_dir, PATH)
        # Construct the full path for the output file
        output_file_path = os.path.join(
            output_dir, os.path.basename(output_file)
        )
        # Ensure that the path exists, and if doesn't is created.
        ensure_path(str(output_dir))

        try:
            self.logger.debug("Recording... Press Ctrl+C to stop.")
            self.open_streams()
            frames = []
            try:
                while True:
                    data = self.input_stream.read(
                        self.CHUNK, exception_on_overflow=False
                    )
                    encrypted_data = self.crypto_manager.encrypt(data)
                    frames.append(encrypted_data)
                    if monitoring:
                        self.output_stream.write(data)
            except KeyboardInterrupt:
                self.logger.debug("\nRecording stopped.")
                with wave.open(output_file, "wb") as wf:
                    wf.setnchannels(self.CHANNELS)
                    wf.setsampwidth(self.audio.get_sample_size(self.FORMAT))
                    wf.setframerate(self.RATE)
                    wf.writeframes(b"".join(frames))
                self.logger.debug(f"Audio saved to {output_file}")
        except PermissionError:
            self.logger.warning(
                f"Permission denied: Unable to write to {output_file}"
            )
        except Exception as e:
            self.logger.error(f"An error occurred: {e}")
        finally:
            self.close_streams()

    def encrypt_file(
        self, input_file=AUDIO_FILE, output_file=ENCRYPTED_AUDIO_FILE
    ):
        """
        Encrypt an audio file and save the encrypted data to a new file.

        Parameters
        ----------
        input_file : str, optional
            The path to the input audio file to be encrypted (default is "audio.wav").
        output_file : str, optional
            The path to the output file where the encrypted audio will be saved (default is "encrypted_audio.bin").
        """
        # Get the parent directory of the current script
        parent_dir = get_proj_root()
        # Create the target folder path in the parent directory
        output_dir = os.path.join(parent_dir, PATH)
        # Construct the full path for the output file
        output_file_path = os.path.join(
            output_dir, os.path.basename(output_file)
        )
        # Ensure that the path exists, and if doesn't is created.
        ensure_path(str(output_dir))

        # Construct the full path for the input file
        input_file_path = os.path.join(
            output_dir, os.path.basename(input_file)
        )

        # Check if the input file exists
        if not os.path.exists(input_file_path):
            self.logger.error(f"Error: {input_file_path} does not exist.")
            return

        with open(input_file_path, "rb") as f:
            audio_data = f.read()

        crypto_manager = CryptoManager()
        encrypted_data = crypto_manager.encrypt(audio_data)

        with open(output_file_path, "wb") as f:
            f.write(encrypted_data)

        self.logger.debug(f"Encrypted audio saved to {output_file}")

    def decrypt_audio_file(
        self, input_file=ENCRYPTED_AUDIO_FILE, output_file=DECRYPTED_AUDIO_FILE
    ):
        """
        Decrypt an encrypted audio file and save the decrypted audio to a new file.

        Parameters
        ----------
        input_file : str, optional
            The encrypted audio file to decrypt (default is "recorded_audio_encrypted.wav").
        output_file : str, optional
            The name of the output WAV file to save decrypted audio (default is "recorded_audio_decrypted.wav").
        """
        # Get the parent directory of the current script
        parent_dir = get_proj_root()
        # Create the target folder path in the parent directory
        output_dir = os.path.join(parent_dir, PATH)
        # Construct the full path for the output file
        output_file_path = os.path.join(
            output_dir, os.path.basename(output_file)
        )
        # Ensure that the path exists, and if doesn't is created.
        ensure_path(str(output_dir))

        # Construct the full path for the input file
        input_file_path = os.path.join(
            output_dir, os.path.basename(input_file)
        )

        # Check if the input file exists
        if not os.path.exists(input_file_path):
            self.logger.error(f"Error: {input_file_path} does not exist.")
            return

        try:
            self.logger.debug(f"Decrypting {input_file}...")
            # Read encrypted data from the file
            with open(input_file, "rb") as encrypted_file:
                encrypted_data = encrypted_file.read()

            # Decrypt the audio data
            decrypted_data = self.crypto_manager.decrypt(encrypted_data)

            # Write the decrypted data to a WAV file
            with wave.open(output_file, "wb") as wf:
                wf.setnchannels(self.CHANNELS)
                wf.setsampwidth(self.audio.get_sample_size(self.FORMAT))
                wf.setframerate(self.RATE)
                wf.writeframes(decrypted_data)

            self.logger.debug(f"Decrypted audio saved to {output_file}")
        except Exception as e:
            self.logger.error(f"An error occurred during decryption: {e}")

    def decrypt_audio_file_chunked(
        self,
        input_file=ENCRYPTED_AUDIO_STREAM_FILE,
        output_file=DECRYPTED_AUDIO_STREAM_FILE,
    ):
        """
        Decrypt an encrypted audio file (chunked frames) and save the decrypted audio to a new file.

        Parameters
        ----------
        input_file : str, optional
            The encrypted audio file to decrypt (default is "recorded_audio_encrypted.wav").
        output_file : str, optional
            The file to save the decrypted audio (default is "recorded_audio_decrypted.wav").
        """
        # Get the parent directory of the current script
        parent_dir = get_proj_root()
        # Create the target folder path in the parent directory
        output_dir = os.path.join(parent_dir, PATH)
        # Construct the full path for the output file
        output_file_path = os.path.join(
            output_dir, os.path.basename(output_file)
        )
        # Ensure that the path exists, and if doesn't is created.
        ensure_path(str(output_dir))

        # Construct the full path for the input file
        input_file_path = os.path.join(
            output_dir, os.path.basename(input_file)
        )

        # Check if the input file exists
        if not os.path.exists(input_file_path):
            self.logger.error(f"Error: {input_file_path} does not exist.")
            return

        try:
            self.logger.debug(f"Decrypting {input_file}...")
            decrypted_frames = []

            # Open the encrypted audio file
            with wave.open(input_file, "rb") as wf:
                # Get parameters from the encrypted file
                num_channels = wf.getnchannels()
                sample_width = wf.getsampwidth()
                frame_rate = wf.getframerate()
                num_frames = wf.getnframes()

                # Read and decrypt frames chunk by chunk
                for _ in range(0, num_frames, self.CHUNK):
                    encrypted_chunk = wf.readframes(self.CHUNK)
                    decrypted_chunk = self.crypto_manager.decrypt(
                        encrypted_chunk
                    )
                    decrypted_frames.append(decrypted_chunk)

            # Write the decrypted frames to a new WAV file
            with wave.open(output_file, "wb") as wf:
                wf.setnchannels(num_channels)
                wf.setsampwidth(sample_width)
                wf.setframerate(frame_rate)
                wf.writeframes(b"".join(decrypted_frames))

            self.logger.debug(f"Decrypted audio saved to {output_file}")
        except Exception as e:
            self.logger.error(f"An error occurred during decryption: {e}")

    def record_encoded_audio(self):
        """
        Record audio from the microphone, encode it using the Opus codec, and save it to a file.

        This method records audio from the microphone, encodes it using the Opus codec,
        and saves the encoded audio to a file.

        Raises
        ------
        KeyboardInterrupt
            Stops recording when Ctrl+C is pressed.
        """
        # Get the parent directory of the current script
        parent_dir = get_proj_root()
        # Create the target folder path in the parent directory
        output_dir = os.path.join(parent_dir, PATH)
        # Construct the full path for the output file
        output_file = os.path.join(output_dir, "recorded_audio.opus")
        # Ensure that the path exists, and if doesn't is created.
        ensure_path(str(output_dir))

        # Open the input stream
        self.open_input_stream()

        # Open file to write encoded audio
        with open(output_file, "wb") as file:
            print("Recording... Press Ctrl+C to stop.")
            try:
                while True:
                    data = self.input_stream.read(
                        self.CHUNK, exception_on_overflow=False
                    )
                    encoded = self.encoder.encode(data, self.CHUNK)

                    # Write the length of the encoded frame first (to aid decoding)
                    file.write(
                        struct.pack("H", len(encoded))
                    )  # Store frame size (2 bytes)
                    file.write(encoded)  # Store actual Opus frame data
            except KeyboardInterrupt:
                print("\nRecording stopped.")
                # Close input stream
                self.input_stream.stop_stream()
                self.input_stream.close()

    def play_encoded_audio(self):
        """
        Play back audio that has been encoded using the Opus codec.

        This method reads an Opus-encoded audio file, decodes it using the Opus codec,
        and plays back the decoded audio.
        """
        # Get the parent directory of the current script
        parent_dir = get_proj_root()
        # Create the target folder path in the parent directory
        output_dir = os.path.join(parent_dir, PATH)
        # Construct the full path for the output file
        input_file = os.path.join(output_dir, "recorded_audio.opus")

        self.open_output_stream()

        # Open file to read encoded audio
        with open(input_file, "rb") as file:
            encoded_data = file.read()

        # Decode Opus audio
        decoded_frames = []
        offset = 0

        while offset < len(encoded_data):
            try:
                # Read stored frame size first
                frame_size = struct.unpack_from("H", encoded_data, offset)[0]
                offset += 2  # Move past the frame size bytes

                # Extract frame data
                chunk = encoded_data[offset : offset + frame_size]
                offset += frame_size  # Move past the actual frame data

                # Decode the frame
                decoded = self.decoder.decode(chunk, self.CHUNK)
                decoded_frames.append(decoded)
            except (opuslib.exceptions.OpusError, struct.error) as e:
                print(f"Opus decoding error: {e}")
                break

        # Combine all decoded frames
        decoded_audio = b"".join(decoded_frames)

        # Play back the decoded audio
        self.output_stream.write(decoded_audio)

        # Close output stream
        self.output_stream.stop_stream()
        self.output_stream.close()

    def encrypt_rsa_file(self, input_file=AUDIO_FILE, output_file=RSA_ENCRYPTED_AUDIO_FILE):
        """
        Encrypt an audio file using RSA and save the encrypted data to a new file.

        Parameters
        ----------
        input_file : str, optional
            The path to the input audio file to be encrypted
        output_file : str, optional
            The path to the output file where the encrypted audio will be saved
        """
        # Get the parent directory of the current script
        parent_dir = get_proj_root()
        output_dir = os.path.join(parent_dir, PATH)
        output_file_path = os.path.join(output_dir, os.path.basename(output_file))
        input_file_path = os.path.join(output_dir, os.path.basename(input_file))
        # Ensure paths exist
        ensure_path(str(output_dir))

        # Check if the input file exists
        if not os.path.exists(input_file_path):
            self.logger.error(f"Error: Input file {input_file_path} does not exist.")
            self.logger.error("Please record an audio file first using option 2 (Record audio).")
            return

        try:
            # Read the audio file
            with wave.open(input_file_path, 'rb') as wf:
                # Get audio parameters
                params = {
                    'channels': wf.getnchannels(),
                    'sampwidth': wf.getsampwidth(),
                    'framerate': wf.getframerate()
                }
                # Read audio data
                audio_data = wf.readframes(wf.getnframes())

            # Encrypt the audio data
            encrypted_data = self.crypto_manager.rsa_encrypt(audio_data)

            # Encrypt the audio data
            with open(output_file_path, "wb") as f:
                f.write(encrypted_data)

            self.logger.info(f"RSA encrypted audio saved to {output_file}")
        except Exception as e:
            self.logger.error(f"An error occurred during encryption: {e}")

    def decrypt_rsa_audio_file(self, input_file=RSA_ENCRYPTED_AUDIO_FILE, output_file=RSA_DECRYPTED_AUDIO_FILE):
        """
        Decrypt an RSA encrypted audio file and save the decrypted audio to a new file.
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

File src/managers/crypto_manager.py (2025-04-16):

"""
Senior Project : Hardware Encryption Device
Team 312
File : crypto_manager.py
Description: This is the cryptography driver for the project. Encyption and decryption is handled
    through this driver class.
"""

""" AES INFO :
The AES mode being used in the CryptoManager class is CFB (Cipher Feedback) mode.

Characteristics of CFB Mode:
    Stream Cipher Emulation:
        CFB mode turns a block cipher like AES into a stream cipher.
        This is useful for encrypting data of arbitrary length, such as audio streams.
    Chaining:
        CFB uses feedback from previous encryption to influence the next block.
        It ensures that identical plaintext blocks produce different ciphertext blocks (assuming a unique IV).
    No Padding Needed:
        Since CFB works on data streams, no padding is required for the plaintext.
    Initialization Vector (IV):
        A unique IV is crucial for ensuring security.
        In the class, a random 16-byte IV is generated (os.urandom(16)) and used.
    Error Propagation:
        Errors in the ciphertext will propagate for the duration of one block size, affecting both encryption and decryption.

Why CFB for Audio?
    CFB mode is suitable for audio streaming because:
        It allows encryption and decryption of partial blocks, making it efficient for real-time processing.
        The lack of padding simplifies the processing pipeline for continuous audio streams.

Other modes:
    GCM (provides integrity/authentication)
    CTR (better parallelism and performance).

"""

import sys
from cryptography.hazmat.primitives.ciphers import Cipher, algorithms, modes
from cryptography.hazmat.primitives.asymmetric import rsa, padding
from cryptography.hazmat.primitives import serialization, hashes

from src.utils.utils import *
from src.utils.constants import (
    PACKET_ENCRYPTION,
    DATA_ENCRYPTION,
    MODE_AES,
    MODE_RSA,
    MODE_HYBRID,
)
from src.logging.logger import *


class CryptoManager:
    """
    Handles encryption and decryption using three different methods:
    1. AES-CFB for stream encryption
    2. RSA for public key encryption
    3. Hybrid RSA-AES for combining the benefits of both

    Attributes
    ----------
    key : bytes
        The AES key for encryption and decryption.
    iv : bytes
        The initialization vector (IV) for encryption and decryption.
    cipher : Cipher
        The AES cipher for encryption and decryption.
    """

    def __init__(
        self,
        key_file="/keys/aes.txt",
        public_key_file="/keys/public_key.pem",
        private_key_file="/keys/private_key.pem",
        hybrid_file="/keys/hybrid.txt",
        hybrid_public_file="/keys/hybrid_public.pem",
        hybrid_private_file="/keys/hybrid_private.pem",
    ):
        """
        Initialize the CryptoManager instance.

        Parameters
        ----------
        key_file : str, optional
            Path to the file containing the AES key and IV.
        """
        # Set up logging
        self.logger: logging = Logger(
            "CryptoManager",
            console_level=logging.INFO,
            console_logging=EN_CONSOLE_LOGGING,
        )

        # Setting up the RSA keys
        self.key_file = str(get_proj_root()) + key_file
        self.private_key_file = str(get_proj_root()) + private_key_file
        self.public_key_file = str(get_proj_root()) + public_key_file
        self.hybrid_file = str(get_proj_root()) + hybrid_file
        self.hybrid_public_file = str(get_proj_root()) + hybrid_public_file
        self.hybrid_private_file = str(get_proj_root()) + hybrid_private_file

        # Setting up the AES key and IV
        self.key, self.iv = self._load_key_iv()
        self.public_key, self.private_key = self._load_rsa_keys()
        self.hybrid_public_key, self.hybrid_private_key = (
            self._load_hybrid_keys()
        )
        self.hybrid_aes_key, self.hybrid_iv = self._load_hybrid_aes_key()

        self.cipher = Cipher(algorithms.AES(self.key), modes.CFB(self.iv))
        self.hybrid_cipher = Cipher(
            algorithms.AES(self.hybrid_aes_key), modes.CFB(self.hybrid_iv)
        )

        # Dictates if Encyption is enabled or not
        self.penc_en = PACKET_ENCRYPTION
        self.denc_en = DATA_ENCRYPTION

        # Sets the encryption mode
        self.mode_aes = MODE_AES
        self.mode_rsa = MODE_RSA
        self.mode_hybrid = MODE_HYBRID

        self.logger.info("CryptoManager initialized")

    def _load_key_iv(self):
        """
        Load the AES key and IV from a file.

        Returns
        -------
        tuple
            A tuple containing the AES key (bytes) and IV (bytes).
        """
        try:
            with open(self.key_file, "r") as f:
                key = bytes.fromhex(f.readline().strip())
                iv = bytes.fromhex(f.readline().strip())
                self.logger.debug("Key and IV loaded from file.")
                return key, iv
        except Exception as e:
            self.logger.error(f"Exception thrown: {e}\nExiting program...")
            sys.exit()

    def _load_rsa_keys(self):
        """
        Load the RSA public and private keys from files.

        Returns
        -------
        tuple
            A tuple containing the RSA public key and private key.
        """
        try:
            with open(self.public_key_file, "rb") as f:
                public_key = serialization.load_pem_public_key(f.read())
            with open(self.private_key_file, "rb") as f:
                private_key = serialization.load_pem_private_key(
                    f.read(), password=None
                )
            self.logger.debug("RSA keys loaded from files.")
            return public_key, private_key
        except Exception as e:
            self.logger.error(f"Exception thrown: {e}\nExiting program...")
            sys.exit()

    def _load_hybrid_keys(self):
        """
        Load the hybrid RSA public and private keys from files.

        Returns
        -------
        tuple
            A tuple containing the hybrid RSA public key and private key.
        """
        try:
            with open(self.hybrid_public_file, "rb") as f:
                public_key = serialization.load_pem_public_key(f.read())
            with open(self.hybrid_private_file, "rb") as f:
                private_key = serialization.load_pem_private_key(
                    f.read(), password=None
                )
            self.logger.debug("Hybrid RSA keys loaded from files.")
            return public_key, private_key
        except Exception as e:
            self.logger.error(f"Exception thrown: {e}\nExiting program...")
            sys.exit()

    def _load_hybrid_aes_key(self):
        """
        Load and decrypt the hybrid AES key from file.
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

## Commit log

2025-01-27 Updated encyption/decryption and audio driver
2025-02-13 Change file destinations for rsa testing, fixes to readme and handlers.
    [audio_manager.py, crypto_manager.py]
2025-03-01 Added thread manager, cleaned up some of the code, added debug screen & functionality.
2025-03-03 Ported adafruit rfm69hcw code to be used on rpi and example to receive based on interrupts.
2025-03-23 Fixed contants, adjusted volume init.
    [audio_manager.py, constants.py, int_stream.py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]
2025-03-30 Added setup script, fixed bugs, added UI to disable encryption, added audio processing, updated docs.
    [base_audio_manager.py, constants.py, crypto_manager.py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]
2025-03-31 Added testing framework, added encryption options in settings ui tab. Updated docs.
2025-04-04 Fixed UI handling inputs
    [display_handler.py]
2025-04-04 Fix to support operation with monitor.
    [base_audio_manager.py]
2025-04-08 Audio device testing.
2025-04-08 Fixed bug where mode not shown if backed out of mode menu.
    [interface_manager.py]
2025-04-08 Update to remove bug if rsa is chosen.
    [rf_manager.py]
2025-04-16 Added more to the readme and added the kicad files.
    [Radio-B_Cu.gbr, Radio-B_Mask.gbr, Radio-B_Paste.gbr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]
